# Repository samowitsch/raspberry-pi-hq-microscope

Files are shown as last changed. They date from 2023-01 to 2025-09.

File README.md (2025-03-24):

# Raspberry Pi HQ microscope

> Current work in progress. Feel free to contribute 😉

## Table of Contents

- [Raspberry Pi HQ microscope](#raspberry-pi-hq-microscope)
  - [Table of Contents](#table-of-contents)
  - [Preface](#preface)
  - [PCB adapter or mount between RPI 3A+ and RPI HQ camera](#pcb-adapter-or-mount-between-rpi-3a-and-rpi-hq-camera)
    - [PCB images](#pcb-images)
    - [Available buttons](#available-buttons)
  - [BOM](#bom)
  - [Software](#software)
    - [SD Card](#sd-card)
    - [Install needed packages](#install-needed-packages)
    - [Cronjobs](#cronjobs)
      - [list running cronjobs](#list-running-cronjobs)
      - [stop running cronjonb process](#stop-running-cronjonb-process)
    - [Python](#python)
  - [Links to other projects or resources](#links-to-other-projects-or-resources)
  - [Videos](#videos)
  - [more pictures](#more-pictures)

## Preface

A small project to build a custom electro microscope based on a Raspberr Pi 3A+ and Raspberry HQ camera. 
But why a 3A+? Because of current delivery problems. The 3A+ has also a normal HDMI port and not such an
fiddly diddly micro hdmi port 😜 Also the form factor and the geekworm case is a good choice.
In fact that it based on a Raspberry Pi it can be modified in any direction.

| | |
| --- | --- |
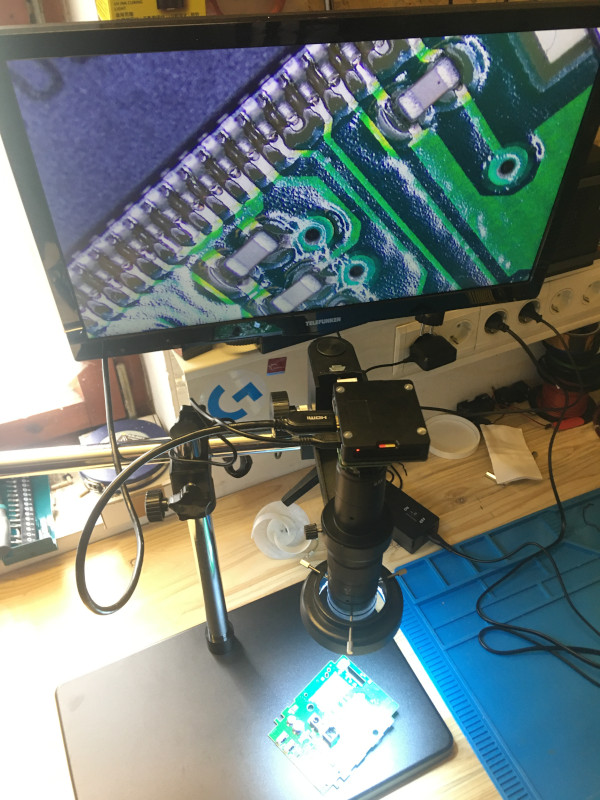
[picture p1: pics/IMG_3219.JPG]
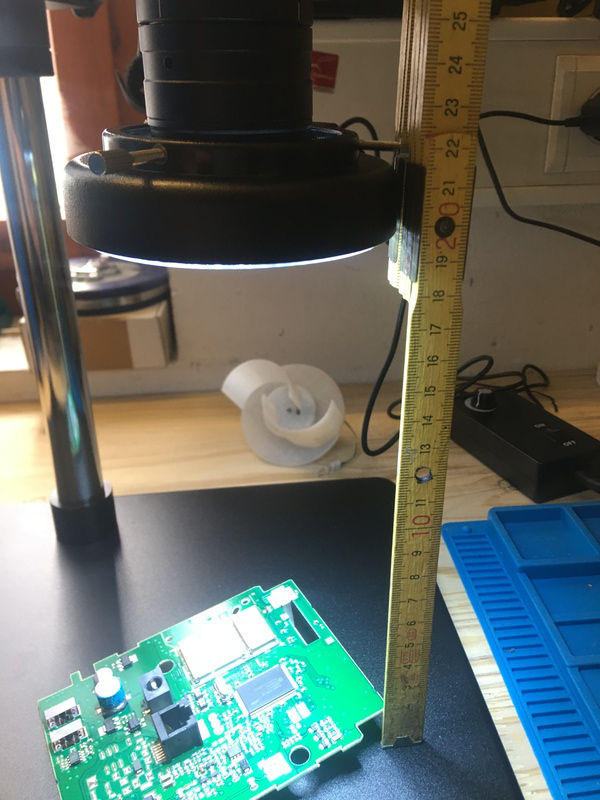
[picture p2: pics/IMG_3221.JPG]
|  |  |
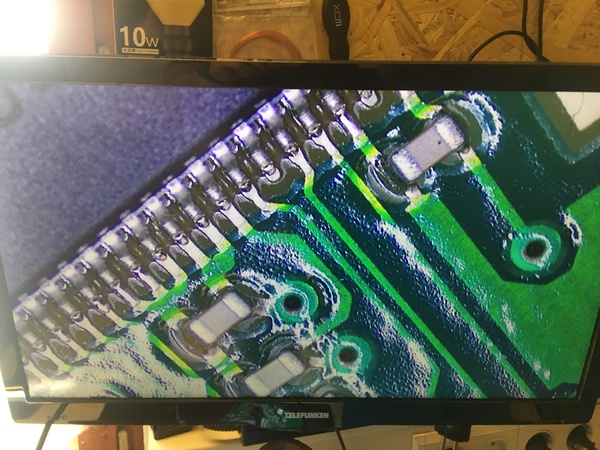
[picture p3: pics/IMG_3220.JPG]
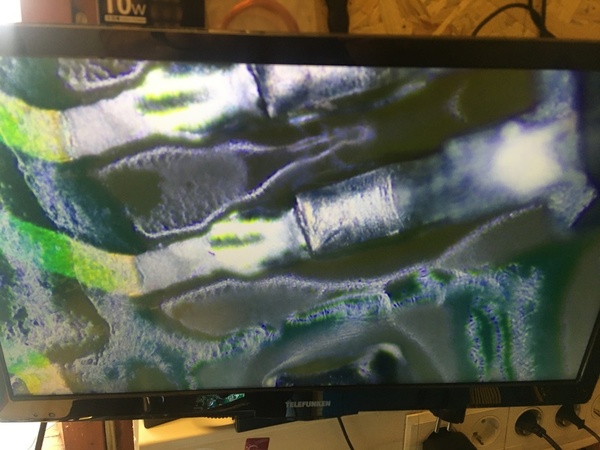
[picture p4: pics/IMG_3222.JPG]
|  |  |

## PCB adapter or mount between RPI 3A+ and RPI HQ camera

The [pcb](pcb/README.md) acts as mounting adapter between the Raspberry Pi 3A+ and the Raspberry Pi HQ Camera. 
It has also 5 buttons that can be used to add custom functions with python.

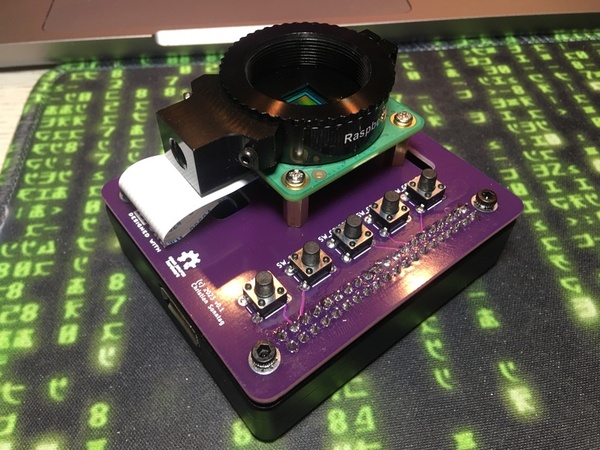
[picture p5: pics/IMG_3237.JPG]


### PCB images

| Front | Back |
| --- | --- |
|  |  |

### Available buttons

| Button | GPIO | Function |
| --- | ---- | --- |
| 1 | 17 | select mode/option |
| 2 | 27 | increase option value |
| 3 | 22 | decrease option value |
| 4 | 19 | capture photo |
| 5 | 26 | shutdown raspi |

## BOM

| Part | Quantity | Description |
| --- | :--- | --- |
|  | 1 | Raspberry Pi 3A+ |
|  | 1 | [Geekworm Raspberry pi case](http://wiki.geekworm.com/P88) |
|  | 1 | Raspberry Pi HQ camera |
|  | 1 | camera cable 6 cm |
|  | 1 | 180x zoom objective with c-mount |
|  | 1 | 0.5x barlow lens |
|  | 1 | LED ring light |
|  | 1 | Heavy duty stand |
|  | 1 (optional) | HDMI 90° adapter |
|  | 1 (optional) | [spacer](spacer/README.md) for the heavy duty stand |
|  | 1 (optional) | USB Wifi dongle **(optional for "better" wifi connectivity)**  |
|  | 1 (optional) | [pcb](pcb/README.md) **(optional. depending to your needs.)** |
|  | 1 (optional) | header female 2x20 pin **(optional. depending to your needs.)** |
|  | 5 (optional) | push button 6x6 **(optional. depending to your needs.)** |

## Software

### SD Card

Prepare Sd-Card with Raspberry Pi OS Lite 32 bit image as usual described in a lot of places in web with [balenaEtcher](https://www.balena.io/etcher?ref=etcher_footer) or similar tool. 
64 bit version of Raspberry Pi OS is not working because needed ```libmmal``` is not available for aarch64.

### Install needed packages

```bash
sudo apt install python3-pip
sudo apt install python3-picamera

pip install picamera
```

### Cronjobs

Starting needed software with crontab on boot. Can vary depending to custom needs. Use ```crontab -e``` to edit the cron jobs.

```
# start simple preview to hdmi output
#@reboot libcamera-still -t 0 --width 1920 --height 1080 --rotation 180 -o current.jpg

# start python script. path to user home can vary in your case
#@reboot sudo python /home/micro/shutdown.py
@reboot sudo python /home/micro/advanced.py
```

#### list running cronjobs

```bash
pstree -apl `pidof cron`

or 

ps aux |grep "/home/micro/advanced.py"

or

ps -o pid,sess,cmd afx | egrep -A20 "( |/)cron( -f)?$"
```

#### stop running cronjonb process

```bash
# stopping process
pkill -s [pid]

#example
pkill -s 424
```

### Python

Scripts for use with cronjob. Place it in the home folder.

* [Simple shutdown only script](src/shutdown.py)
* [Advanced script](src/advanced.py)

## Links to other projects or resources

* [Thingiverse: Pi Mocroscope](https://www.thingiverse.com/thing:3920261)
* [hackaday.io: Pi Microscope](https://hackaday.io/project/167996-pi-microscope)
* [Github: amphioxus/raspi_camera_scripts](https://github.com/raspberrypi/picamera2)
* [Github: raspberrypi/picamera2](https://github.com/amphioxus/raspi_camera_scripts)
* [element14 community: I Spy With My Digital Eye .... a Pico PI](https://community.element14.com/challenges-projects/project14/offtheshelf/b/blog/posts/i-spy-with-my-digital-eye-a-pico-pi)
* [Picamera 1.13 readthedocs](https://picamera.readthedocs.io/en/release-1.13/)
* [Picamera 2 library pdf](https://datasheets.raspberrypi.com/camera/picamera2-manual.pdf)
* [Geekworm Raspberry pi case](http://wiki.geekworm.com/P88)

## Videos

* [YT Video Part 1](https://www.youtube.com/watch?v=33pAQVsLFqw&ab_channel=daSamo123)
* [YT Video Part 2](https://www.youtube.com/watch?v=zNRziszGEiE&ab_channel=daSamo123)

## more pictures

[More pictures](README-more-pics.md)

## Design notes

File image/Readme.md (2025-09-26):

# Readme

## Description
Here you can find a shrinked zipped image of the current state. It was generated with the [PiShrink](https://github.com/Drewsif/PiShrink/tree/master) script and can be written back to sd card or usb stick with [Balena Etcher](https://etcher.balena.io).

## User
User is ```micro``` with password ```micro```

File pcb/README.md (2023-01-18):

# PCB adapter or mount between RPI and RPI HQ camera

For more details see. KiCad files.



| Front | Back |
| --- | --- |
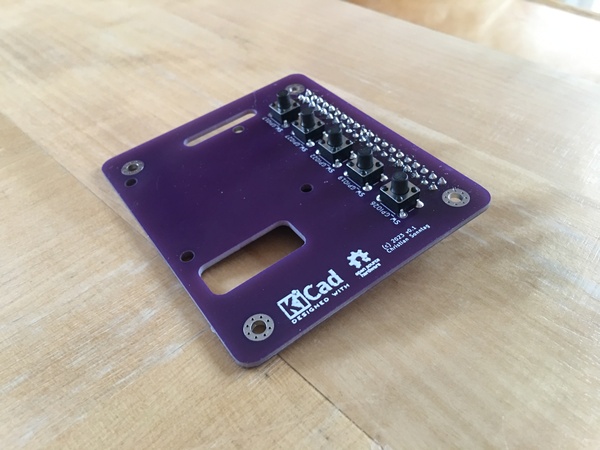
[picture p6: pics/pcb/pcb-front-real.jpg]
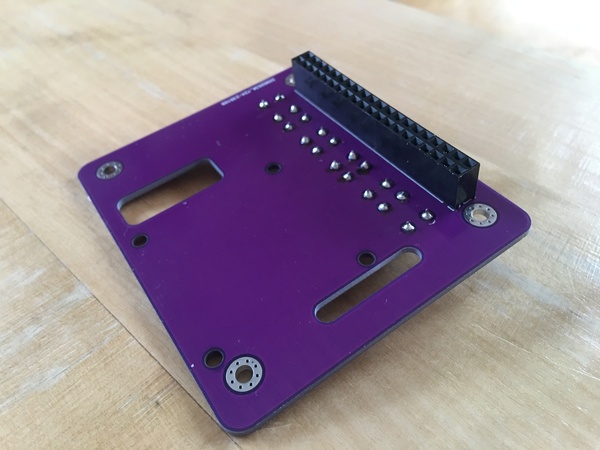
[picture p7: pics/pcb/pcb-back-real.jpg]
|  |  |

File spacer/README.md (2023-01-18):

# Spacer for the heavy duty stand

This is a spacer to add more distance between the stand and the swivel arm.  

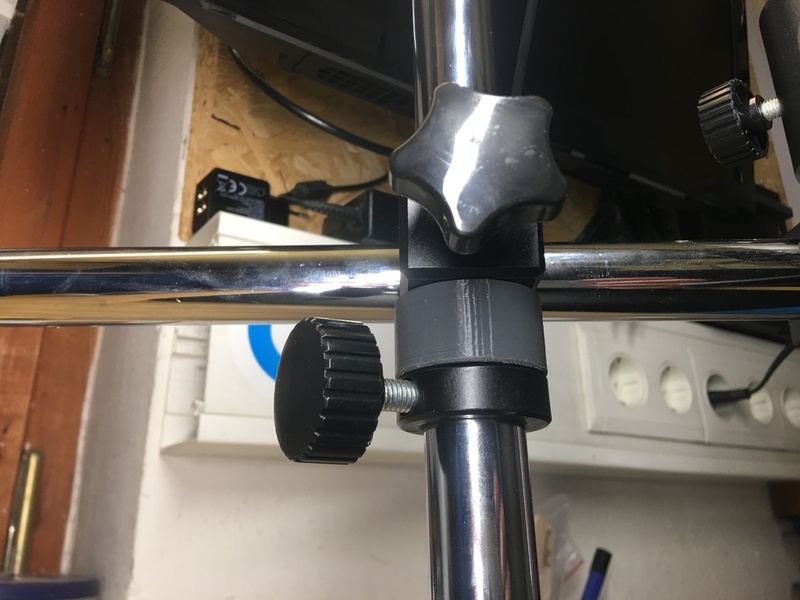
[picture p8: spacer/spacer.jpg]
  

It is created with OpenSCAD.

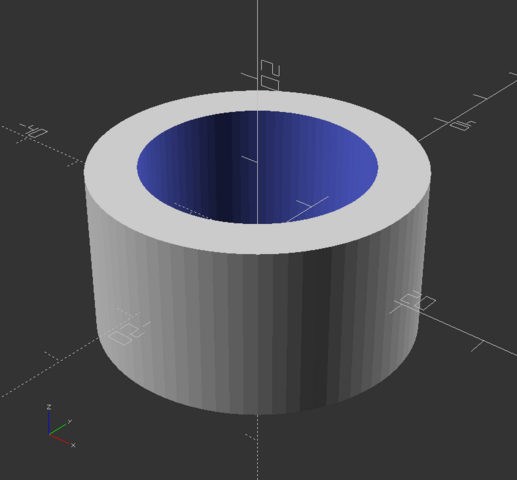
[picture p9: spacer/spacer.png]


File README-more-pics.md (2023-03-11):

# Raspberry Pi HQ microscope more pics

Here are some more pictures where the RPI 3A+ is mounted without case.

| | |
| --- | --- |
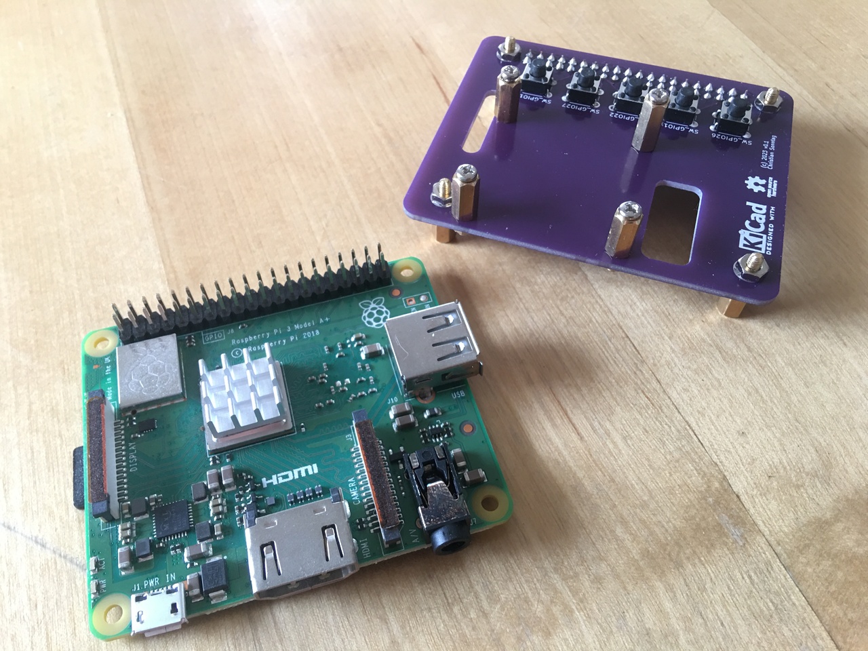
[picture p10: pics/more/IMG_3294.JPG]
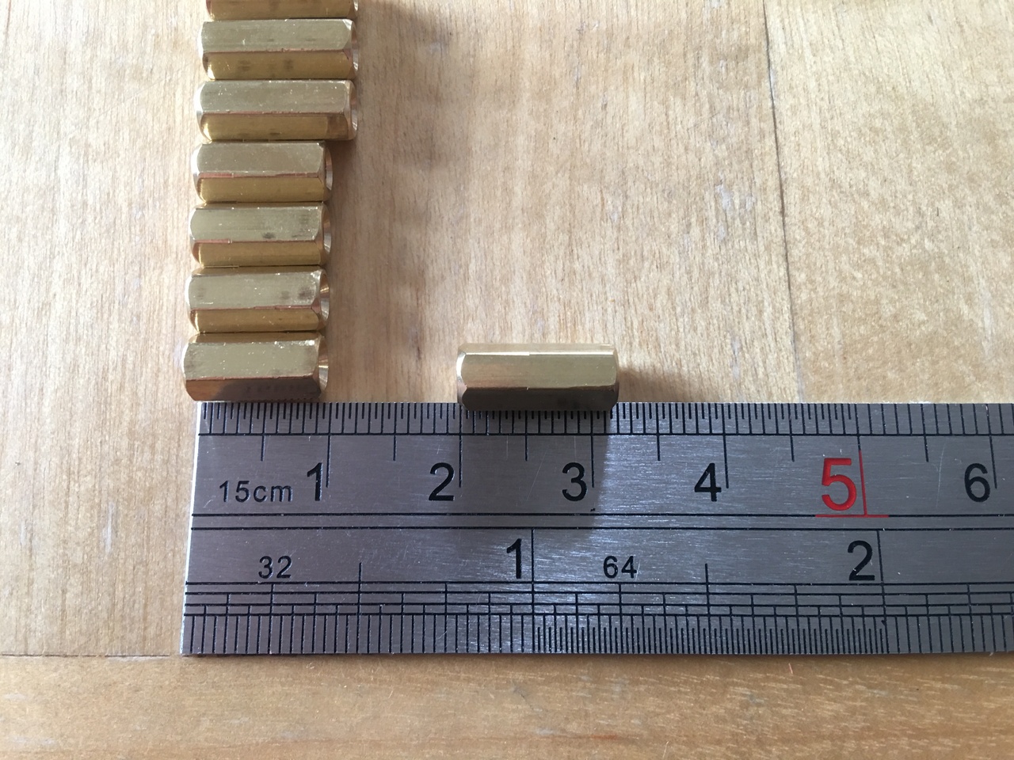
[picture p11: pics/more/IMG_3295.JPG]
|  |  |
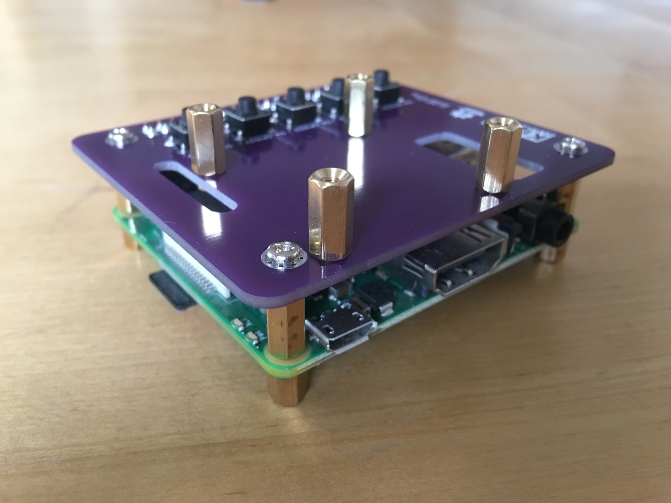
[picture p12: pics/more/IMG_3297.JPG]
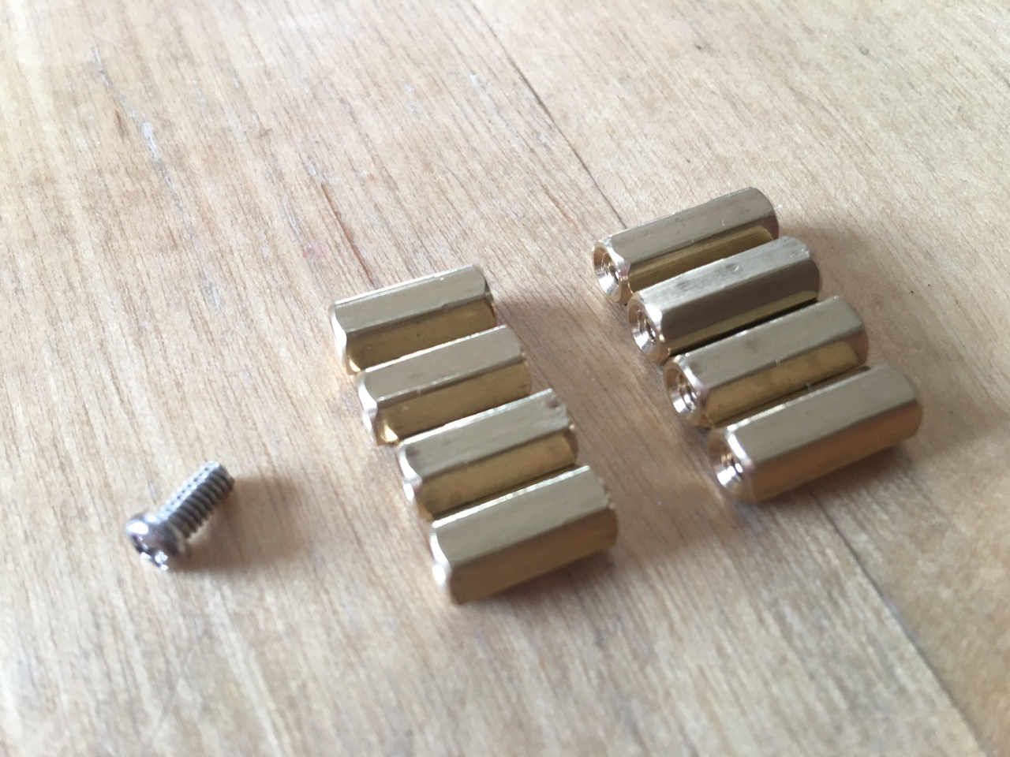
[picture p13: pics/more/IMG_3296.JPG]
|  |  |
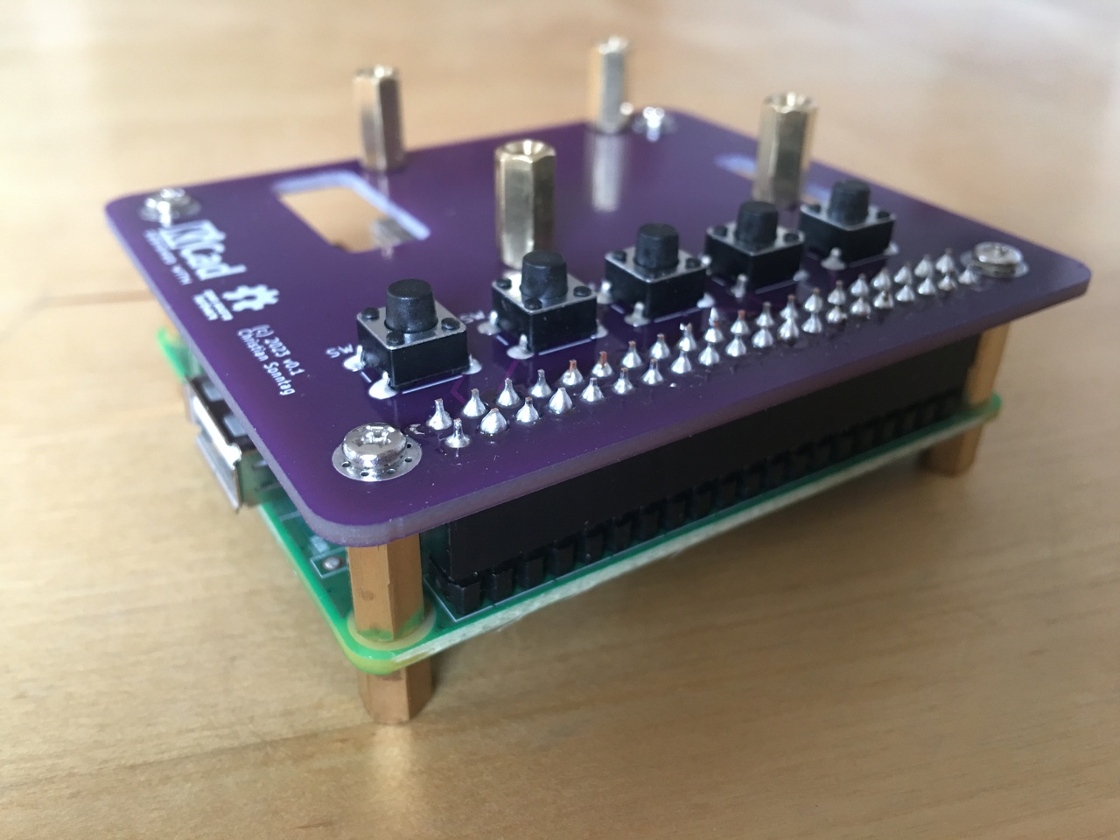
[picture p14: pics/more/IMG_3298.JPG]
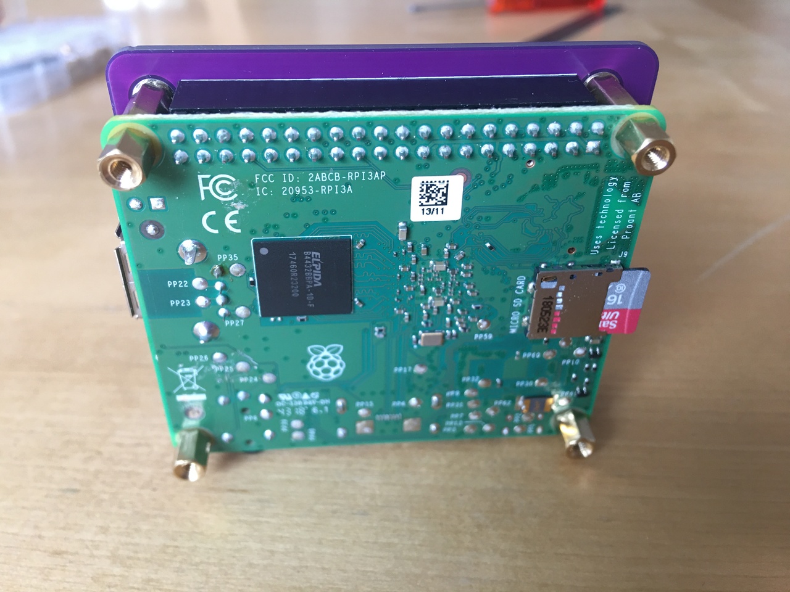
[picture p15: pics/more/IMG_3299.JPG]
|  |  |
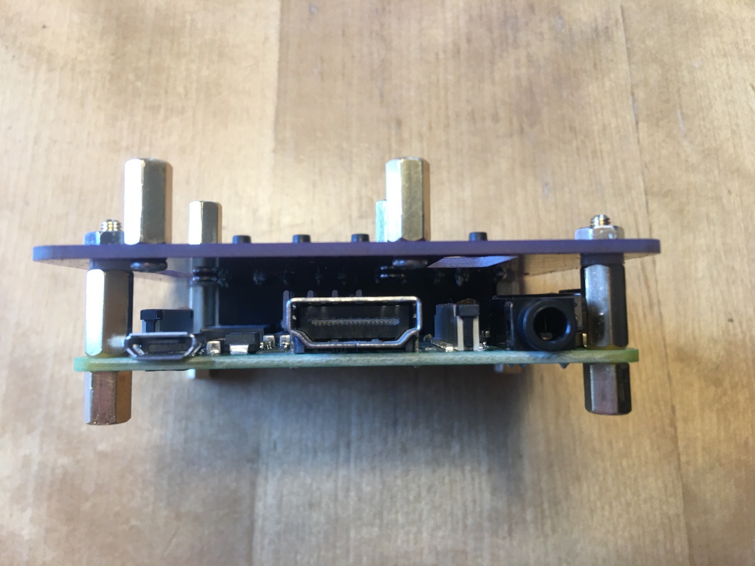
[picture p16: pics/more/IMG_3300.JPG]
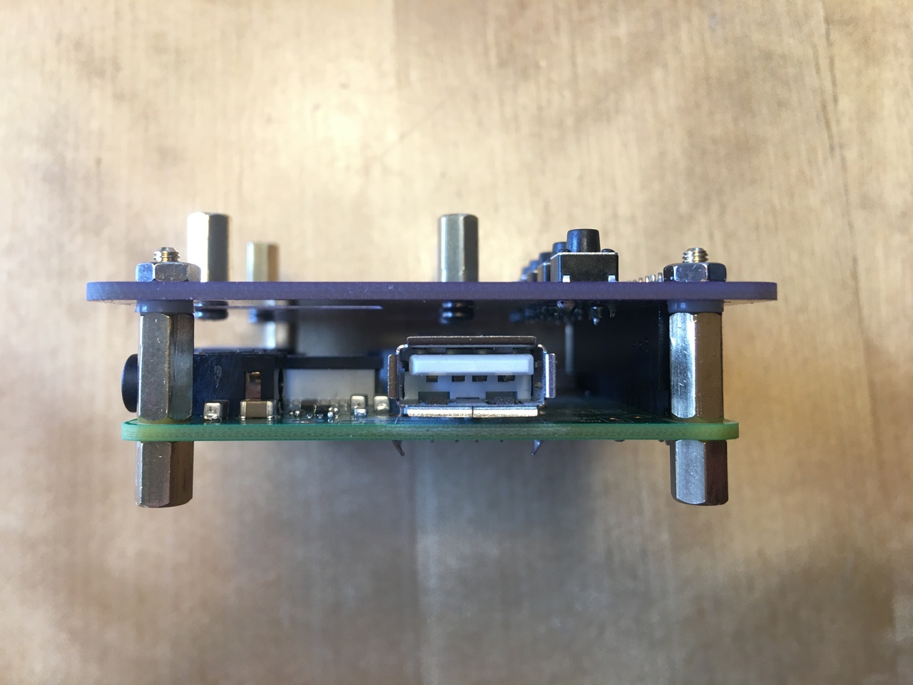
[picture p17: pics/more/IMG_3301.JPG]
|  |  |
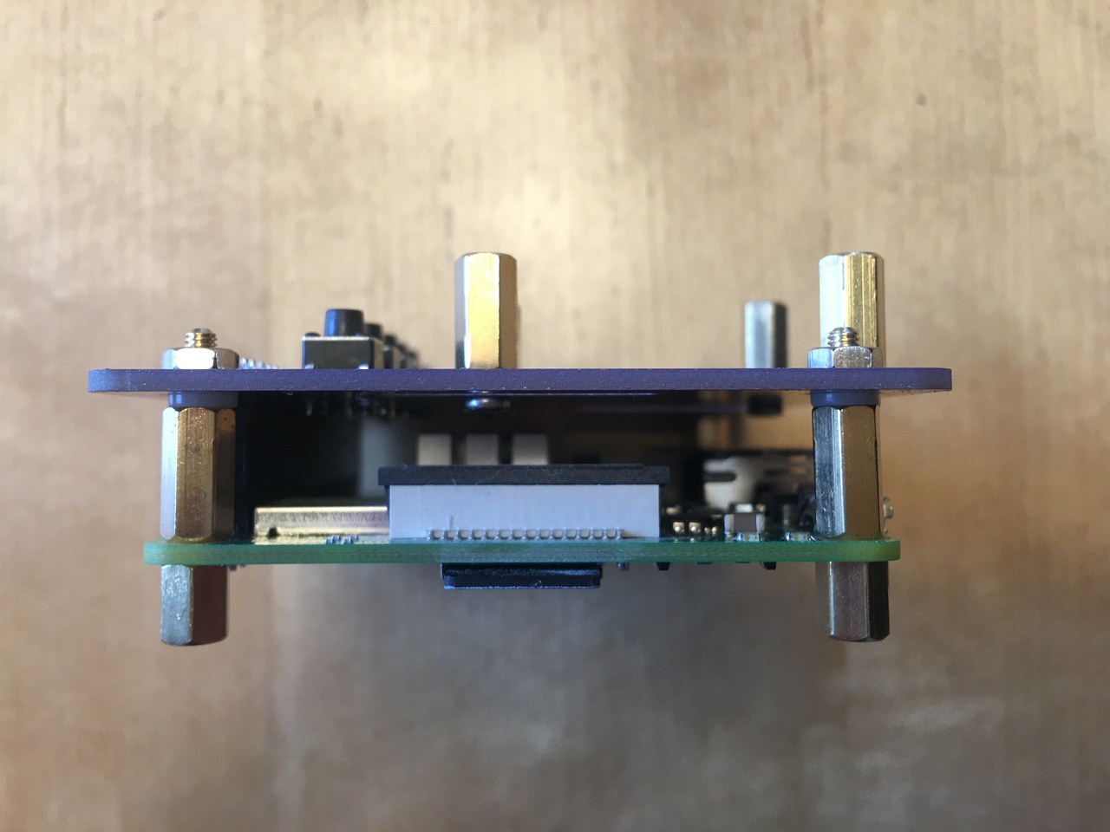
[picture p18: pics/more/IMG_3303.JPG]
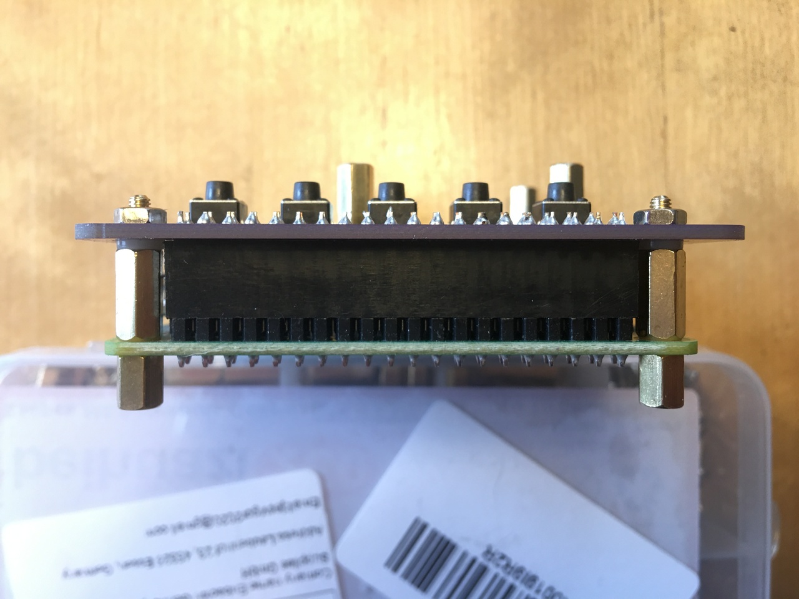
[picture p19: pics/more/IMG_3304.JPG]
|  |  |
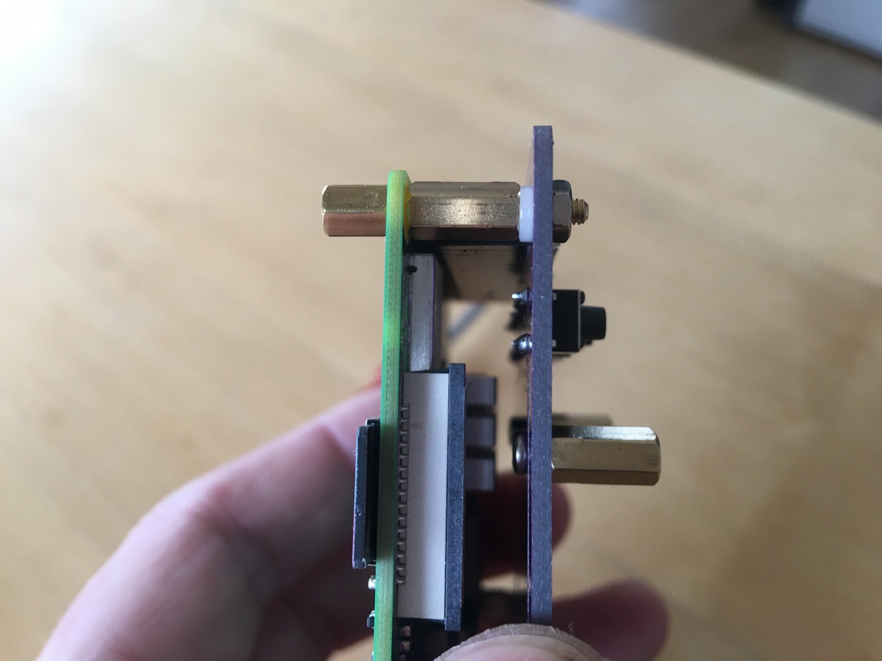
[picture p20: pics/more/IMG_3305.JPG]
|  | |
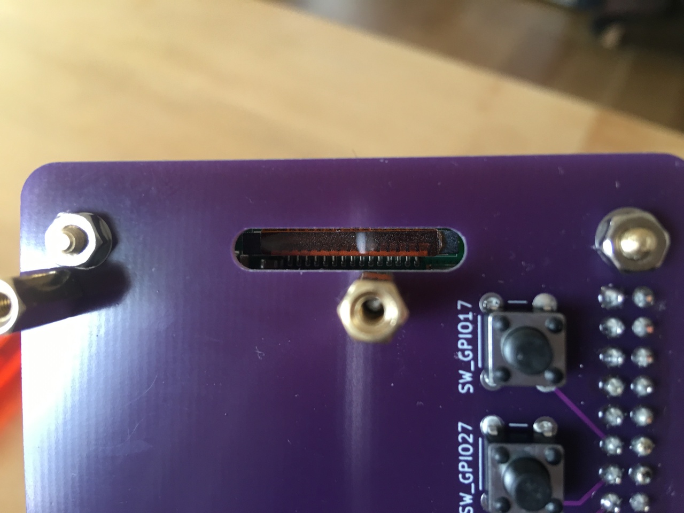
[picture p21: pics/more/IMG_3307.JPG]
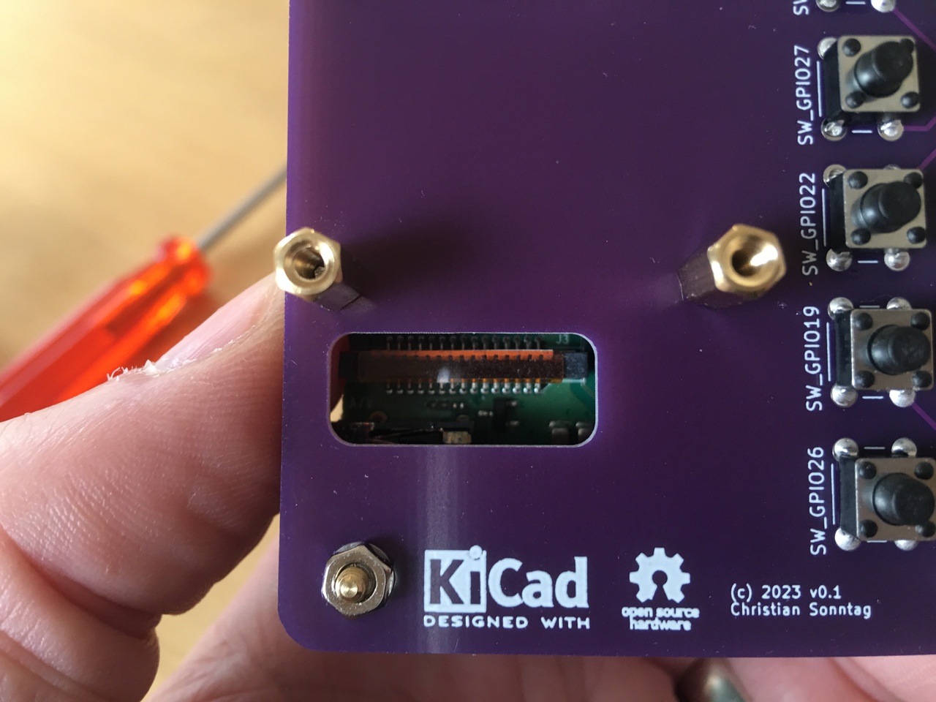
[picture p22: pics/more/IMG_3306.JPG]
|  |  |

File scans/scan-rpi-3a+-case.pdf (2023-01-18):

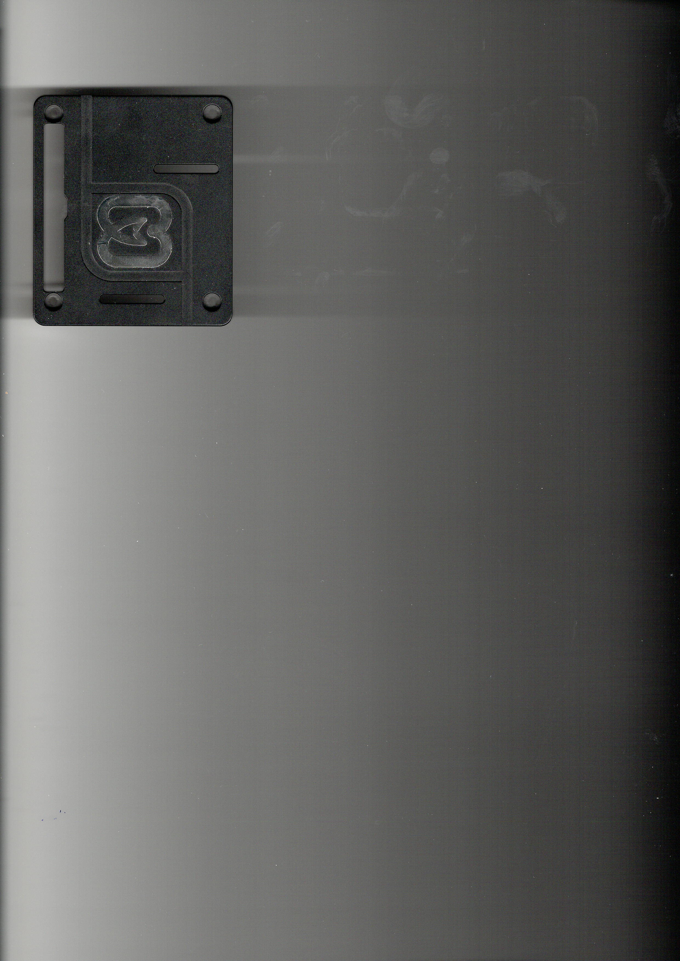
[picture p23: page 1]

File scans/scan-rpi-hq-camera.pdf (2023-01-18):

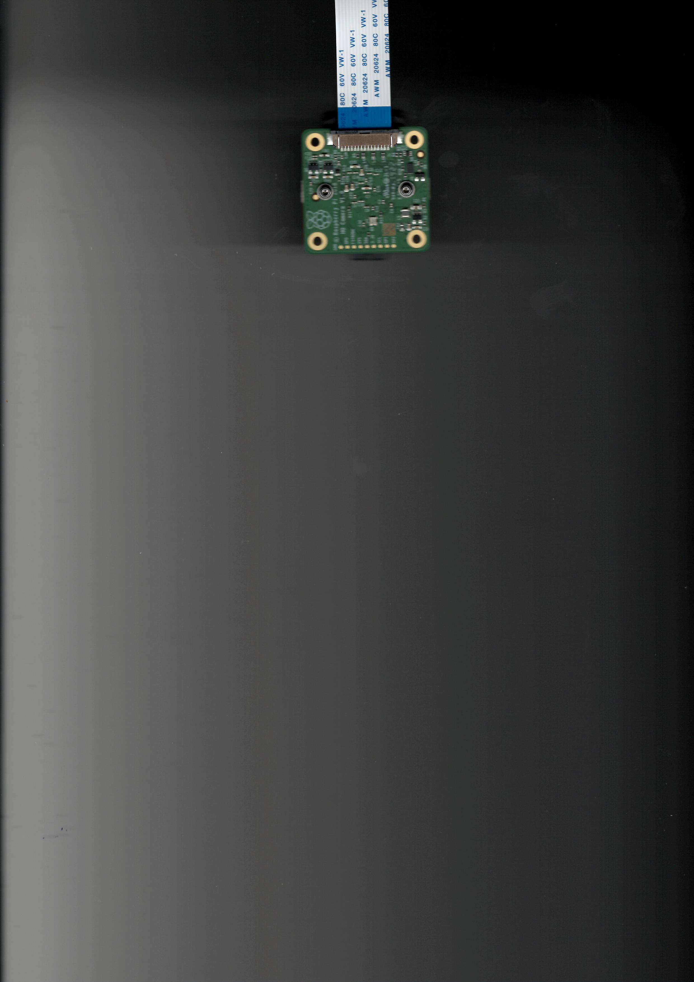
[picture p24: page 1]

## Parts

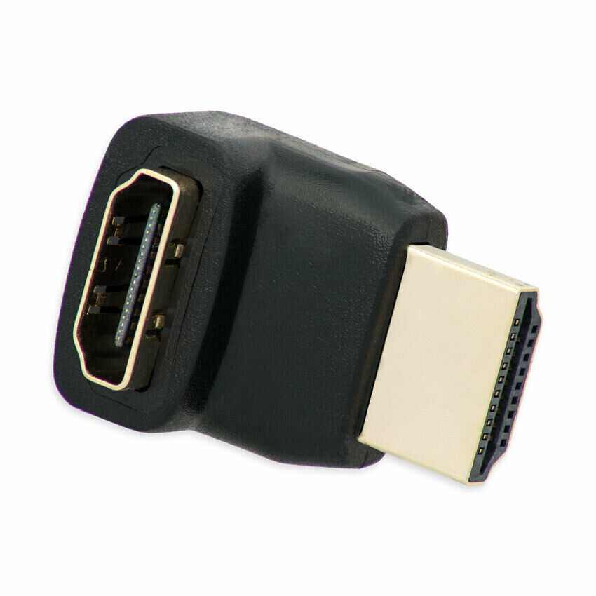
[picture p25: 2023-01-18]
pics/bom/hdmi-90-adapter.jpg

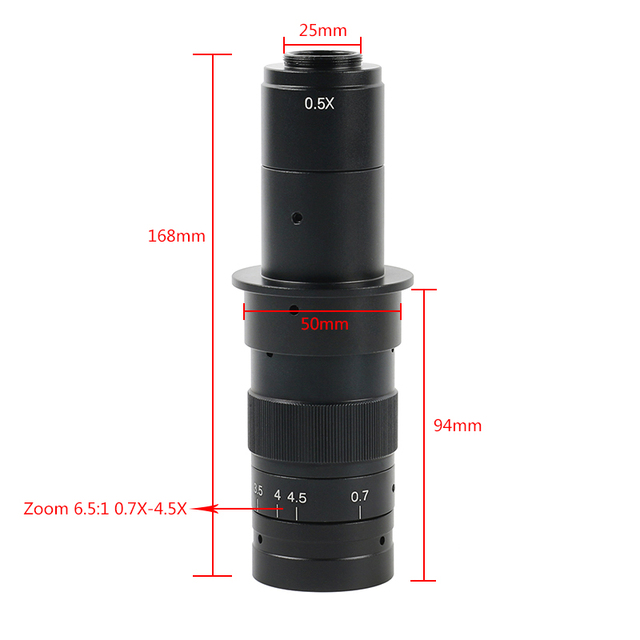
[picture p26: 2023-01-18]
pics/bom/c-mount-180x-zoom-objective.jpg

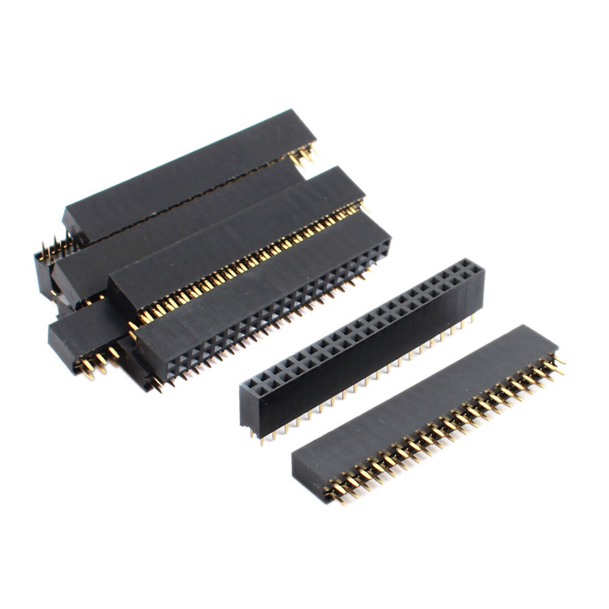
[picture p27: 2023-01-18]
pics/bom/header-female-40pin-2x20.jpg

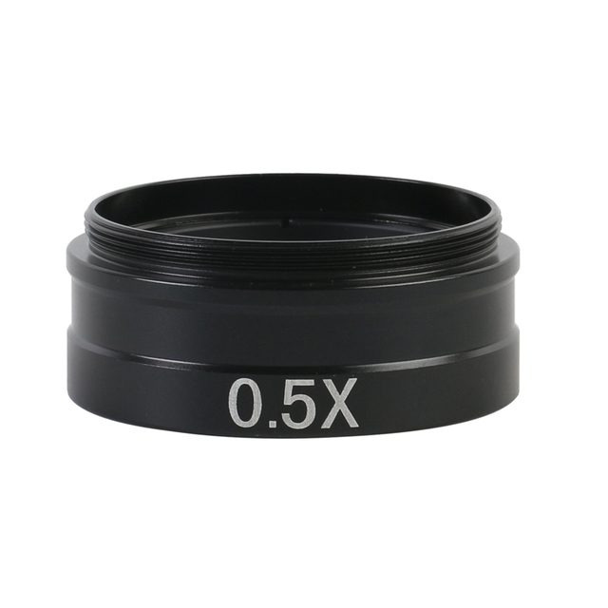
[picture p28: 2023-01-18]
pics/bom/barlow-lens-0.5x.jpg

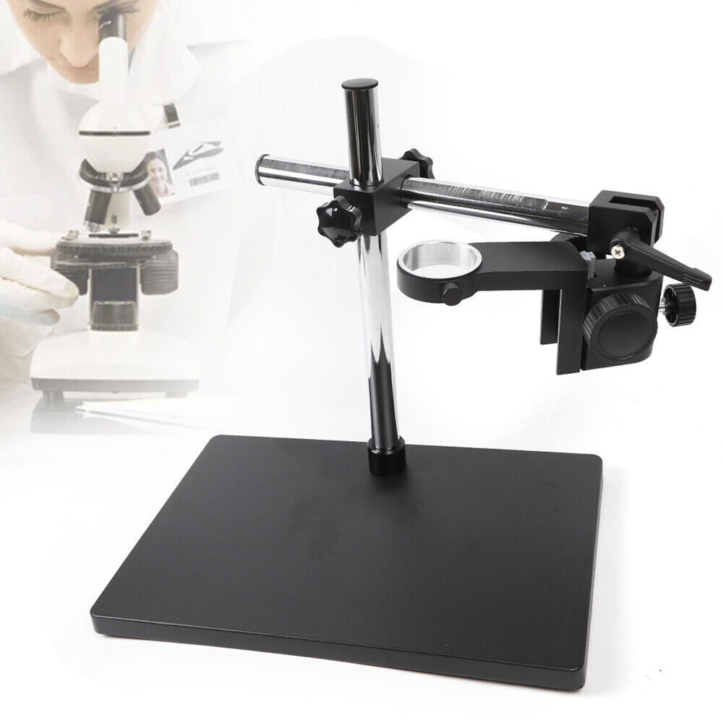
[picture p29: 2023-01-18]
pics/bom/heavy-duty-stand.jpg

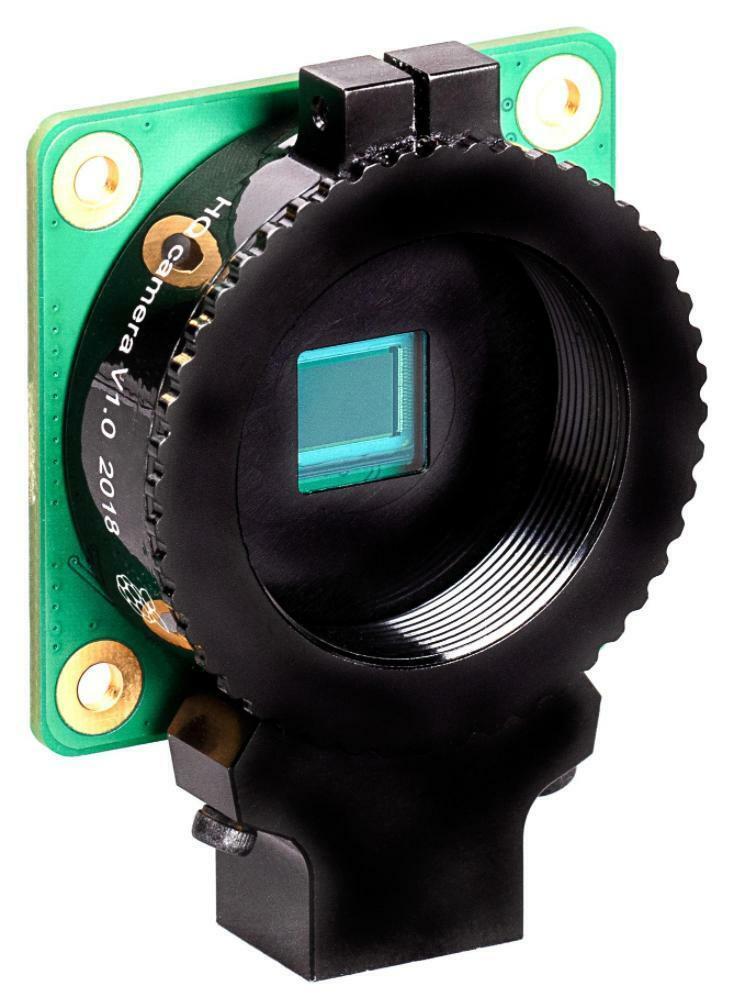
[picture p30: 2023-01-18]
pics/bom/rpi-hq-camera.jpg

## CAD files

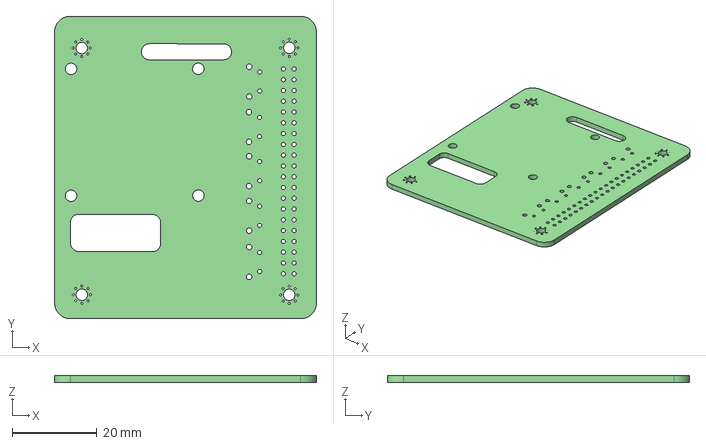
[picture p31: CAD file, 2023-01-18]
pcb/pcb.step
61.7 x 71.3 x 1.60 mm

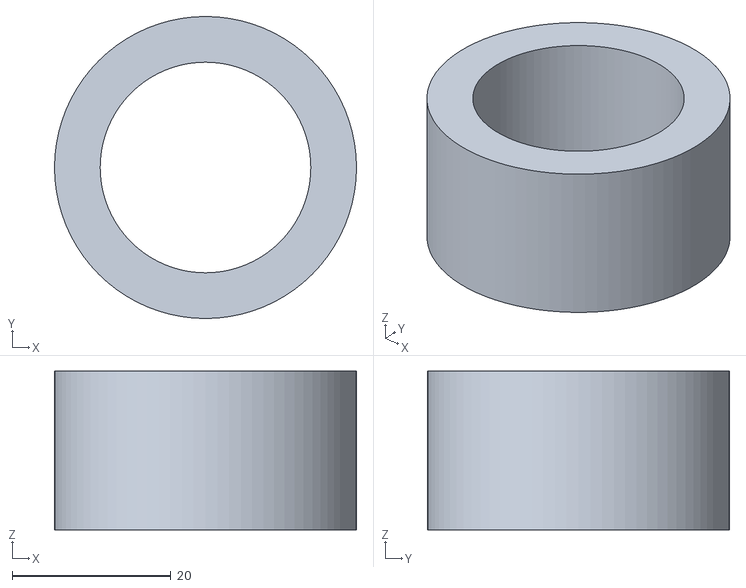
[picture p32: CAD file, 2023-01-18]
spacer/microscope-spacer.stl
38.0 x 38.0 x 20.0

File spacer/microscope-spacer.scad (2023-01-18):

$fn = 80;
difference(){
  cylinder(h = 20, d = 38, center = true);
  cylinder(h = 20, d = 26.5, center = true);
}

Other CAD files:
pcb/pcb.stl

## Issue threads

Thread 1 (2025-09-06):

Lens info??

SoLongSidekick, 2025-09-06:
Hi,

Love the project as I've been prototyping a version of something very similar. However I noticed the lens you are using is not the typical Waveshare microscope lens ([viewable here](https://www.pishop.us/product/100x-industrial-microscope-lens-c-cs-mount-compatible-with-raspberry-pi-hq-camera-cs/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)) but there isn't any info or source for your version, and the only image attached is thumbnail size so the specs on the image can't be read. Do you have any more information on it? A part number and brand/source would be amazing.

Also, what are you using the barlow lens for? I'm super curious as it seems like I may have missed something in my design.

Thanks in advance!

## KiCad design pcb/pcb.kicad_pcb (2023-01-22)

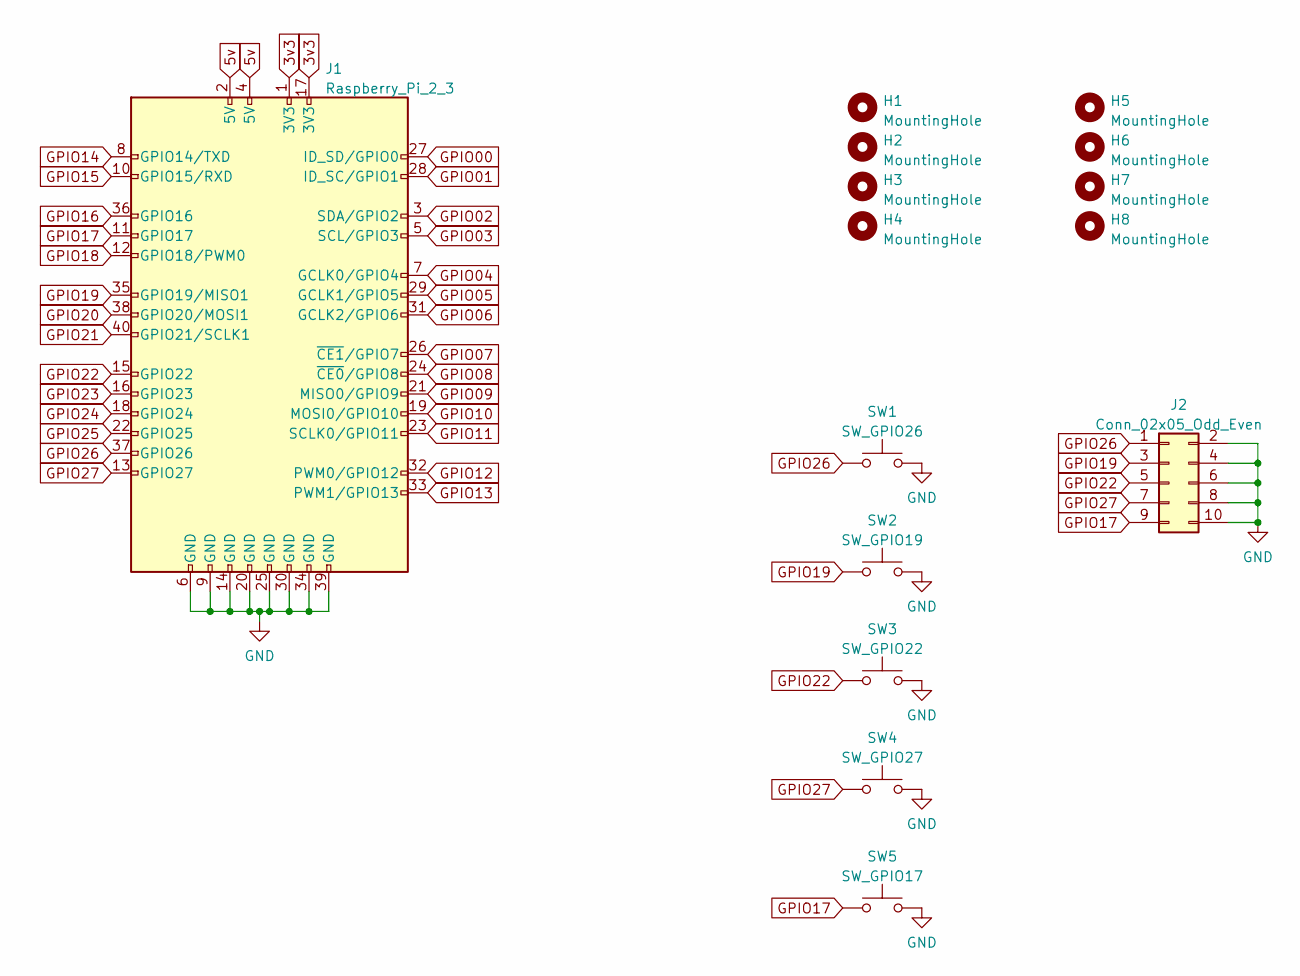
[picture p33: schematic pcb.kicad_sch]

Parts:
H1, H2, H3, H4: MountingHole; MountingHole_2.7mm_M2.5_Pad_Via
H5, H6, H7, H8: MountingHole; MountingHole_2.7mm
J1: Raspberry_Pi_2_3; PinSocket_2x20_P2.54mm_Vertical
J2: Conn_02x05_Odd_Even; PinHeader_2x05_P2.54mm_Vertical
SW1: SW_GPIO26; SW_PUSH_6mm_H5mm
SW2: SW_GPIO19; SW_PUSH_6mm_H5mm
SW3: SW_GPIO22; SW_PUSH_6mm_H5mm
SW4: SW_GPIO27; SW_PUSH_6mm_H5mm
SW5: SW_GPIO17; SW_PUSH_6mm_H5mm

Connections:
3v3: J1.1 (3V3), J1.17 (3V3)
5v: J1.2 (5V), J1.4 (5V)
GND: J1.6 (GND), J1.9 (GND), J1.14 (GND), J1.20 (GND), J1.25 (GND), J1.30 (GND), J1.34 (GND), J1.39 (GND), J2.2, J2.4, J2.6, J2.8, J2.10, SW1.2, SW2.2, SW3.2, SW4.2, SW5.2
GPIO00: J1.27 (ID_SD/GPIO0)
GPIO01: J1.28 (ID_SC/GPIO1)
GPIO02: J1.3 (SDA/GPIO2)
GPIO03: J1.5 (SCL/GPIO3)
GPIO04: J1.7 (GCLK0/GPIO4)
GPIO05: J1.29 (GCLK1/GPIO5)
GPIO06: J1.31 (GCLK2/GPIO6)
GPIO07: J1.26 (~CE1/GPIO7)
GPIO08: J1.24 (~CE0/GPIO8)
GPIO09: J1.21 (MISO0/GPIO9)
GPIO10: J1.19 (MOSI0/GPIO10)
GPIO11: J1.23 (SCLK0/GPIO11)
GPIO12: J1.32 (PWM0/GPIO12)
GPIO13: J1.33 (PWM1/GPIO13)
GPIO14: J1.8 (GPIO14/TXD)
GPIO15: J1.10 (GPIO15/RXD)
GPIO16: J1.36 (GPIO16)
GPIO17: J1.11 (GPIO17), J2.9, SW5.1
GPIO18: J1.12 (GPIO18/PWM0)
GPIO19: J1.35 (GPIO19/MISO1), J2.3, SW2.1
GPIO20: J1.38 (GPIO20/MOSI1)
GPIO21: J1.40 (GPIO21/SCLK1)
GPIO22: J1.15 (GPIO22), J2.5, SW3.1
GPIO23: J1.16 (GPIO23)
GPIO24: J1.18 (GPIO24)
GPIO25: J1.22 (GPIO25)
GPIO26: J1.37 (GPIO26), J2.1, SW1.1
GPIO27: J1.13 (GPIO27), J2.7, SW4.1

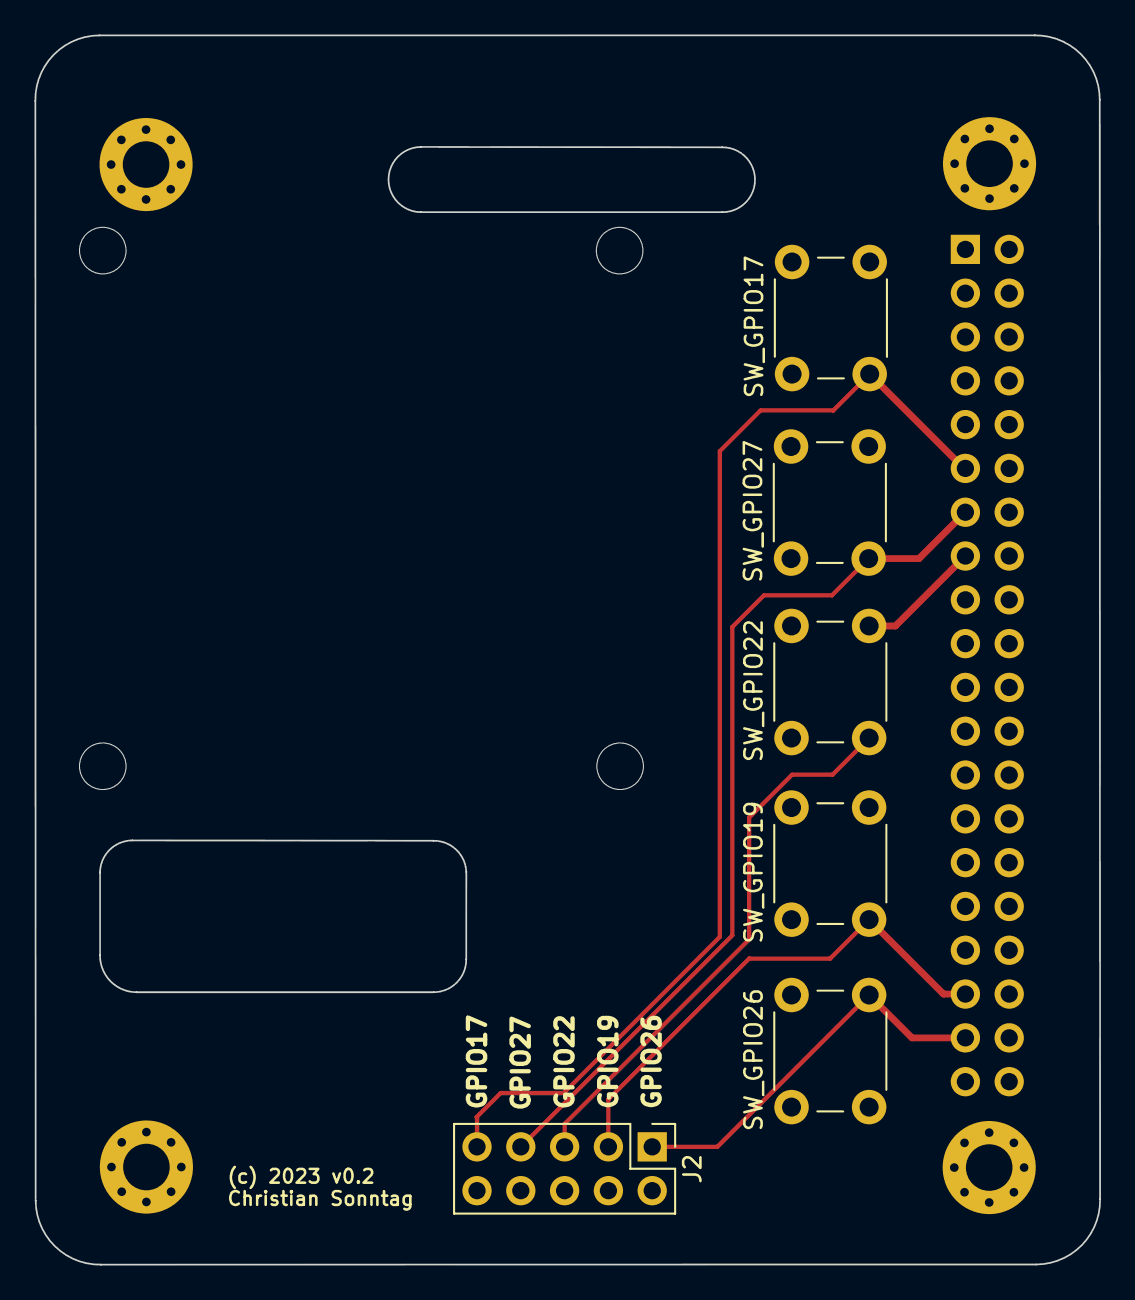
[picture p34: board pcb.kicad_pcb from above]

Board: 2 copper layers, 61.7 x 71.3 mm, 15 parts (1 on the bottom side), 8 nets.

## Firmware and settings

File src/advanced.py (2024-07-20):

import picamera
from PIL import Image, ImageFont, ImageDraw 
import RPi.GPIO as GPIO
import time
import os
import sys
import logging

logging.basicConfig(
    level=logging.INFO,
    format="%(asctime)s [%(levelname)s] %(message)s",
    handlers=[
        logging.FileHandler("advanced.log"),
        logging.StreamHandler(sys.stdout)
    ]
)

camera = picamera.PiCamera()
camera.resolution = (1920, 1080)
camera.rotation = 180
camera.framerate = 30
camera.start_preview()


img = Image.open('overlay.png')
draw = ImageDraw.Draw(img)
font = ImageFont.truetype("/usr/share/fonts/truetype/dejavu/DejaVuSans-Bold.ttf", 34)
draw.text((10, 5), "RPI 3A+ HQ Cam Microscope v0.1", font=font, align ="left")

pad = Image.new('RGBA', (
    ((img.size[0] + 31) // 32) * 32,
    ((img.size[1] + 15) // 16) * 16,
    ))

pad.paste(img, (0, 0))

o = camera.add_overlay(pad.tobytes(), size=img.size, layer=3, alpha = 254)
#camera.remove_overlay(o)

# gpio buttons of the pcb adapter board
BTN_CAPTURE = 17
BTN_MODE = 27
BTN_INCREASE = 22
BTN_DECREASE = 19
BTN_SHUTDOWN = 26

# path to capture. depending to username and your custom needs
PATH_CAPTURE = "/home/micro/capture/"

GPIO.setmode(GPIO.BCM)
GPIO.setup(BTN_MODE, GPIO.IN, pull_up_down=GPIO.PUD_UP)
GPIO.setup(BTN_INCREASE, GPIO.IN, pull_up_down=GPIO.PUD_UP)
GPIO.setup(BTN_DECREASE, GPIO.IN, pull_up_down=GPIO.PUD_UP)
GPIO.setup(BTN_CAPTURE, GPIO.IN, pull_up_down=GPIO.PUD_UP)
GPIO.setup(BTN_SHUTDOWN, GPIO.IN, pull_up_down=GPIO.PUD_UP)


def mode_select(channel):
    logging.info("Pressed mode")
    time.sleep(1)

def increase(channel):
    logging.info("Increase value")
    time.sleep(1)

def decrease(channel):
    logging.info("Decrease value")
    time.sleep(1)

def capture_photo(channel):
    logging.info("Capture photo")
    t = time.localtime()
    filename = PATH_CAPTURE + "capture" + time.strftime('-%Y-%m-%d_%H-%M-%S', t) + ".jpg"
    camera.capture(filename)

    # owner:group can vary depending to in sd card setup given username
    os.system("chown micro:micro " + filename)

def shutdown(channel):
    logging.info("Shutting down")
    time.sleep(1)
    os.system("sudo shutdown -h now")

GPIO.add_event_detect(BTN_MODE, GPIO.FALLING, callback=mode_select, bouncetime=1100)
GPIO.add_event_detect(BTN_INCREASE, GPIO.FALLING, callback=increase, bouncetime=1100)
GPIO.add_event_detect(BTN_DECREASE, GPIO.FALLING, callback=decrease, bouncetime=1100)
GPIO.add_event_detect(BTN_CAPTURE, GPIO.FALLING, callback=capture_photo, bouncetime=1100)
GPIO.add_event_detect(BTN_SHUTDOWN, GPIO.FALLING, callback=shutdown, bouncetime=1100)

logging.info("Advanced script started")
while 1:
    time.sleep(1)

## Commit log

2023-01-22 Revert "refactor time object to capture placeholder" It seems placeholder works only with capture_continuous ;-(
    This reverts commit c0ef082705d468f20181cc083df675ff02a56d62.
    [advanced.py]
2023-01-22 change button mapping. use button in front to capture images.
2023-01-22 add additional pinheader as alternative to button switches
    [pcb-B_Cu.gbr, pcb-B_Mask.gbr, pcb-B_Paste.gbr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]

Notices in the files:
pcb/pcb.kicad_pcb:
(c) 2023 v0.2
